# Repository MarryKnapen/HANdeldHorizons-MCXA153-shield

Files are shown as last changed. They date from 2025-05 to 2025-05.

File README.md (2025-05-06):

# FRDM-MCXA153 Arduino + MirkoBUS shield KICAD template

- Can be converted to Arduino Only or MikroBUS only template

# DO NOT USE THIS TEMPLATE, NO GUARANTEE IS GIVEN. THIS PRODUCT IS INCOMPLETE AND STILL REQUIRES PHYSICAL VERIFICATION OF COMPATIBILITY

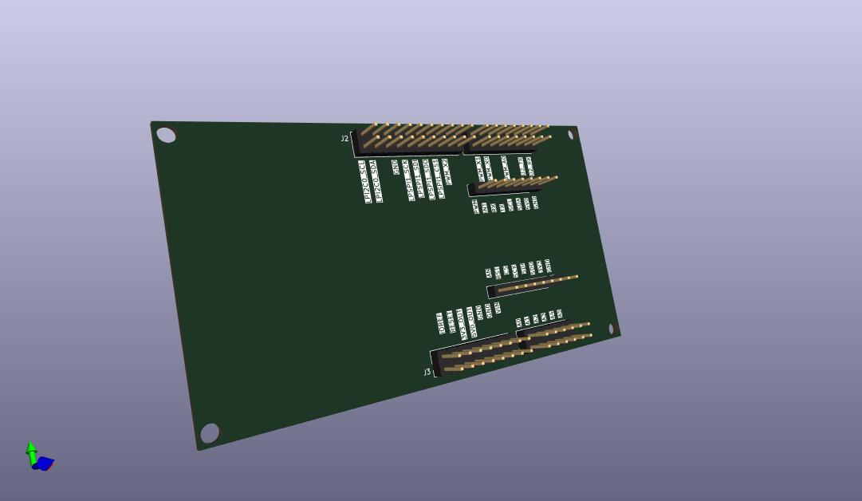
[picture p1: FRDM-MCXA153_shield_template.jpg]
template


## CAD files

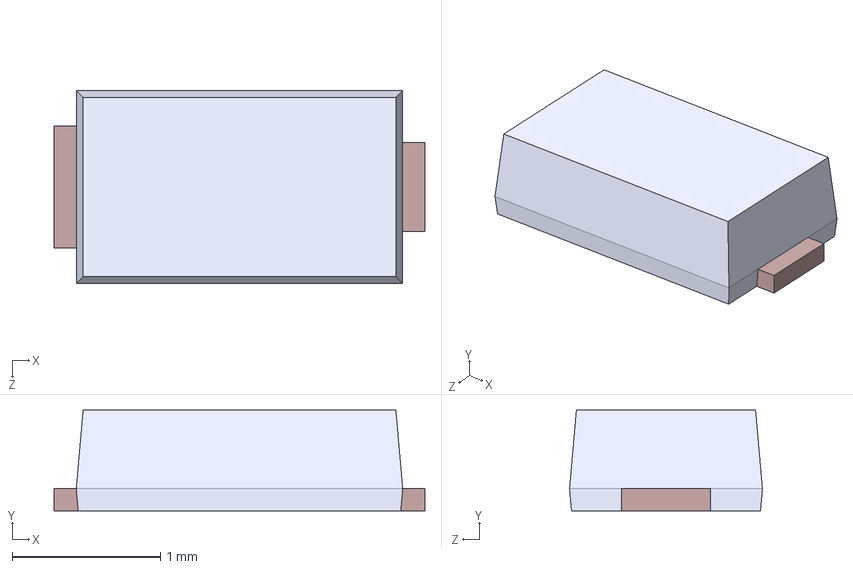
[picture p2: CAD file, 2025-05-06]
components/MSS1P3L_M3_89A/MSMP package.step
2.50 x 0.68 x 1.30 mm

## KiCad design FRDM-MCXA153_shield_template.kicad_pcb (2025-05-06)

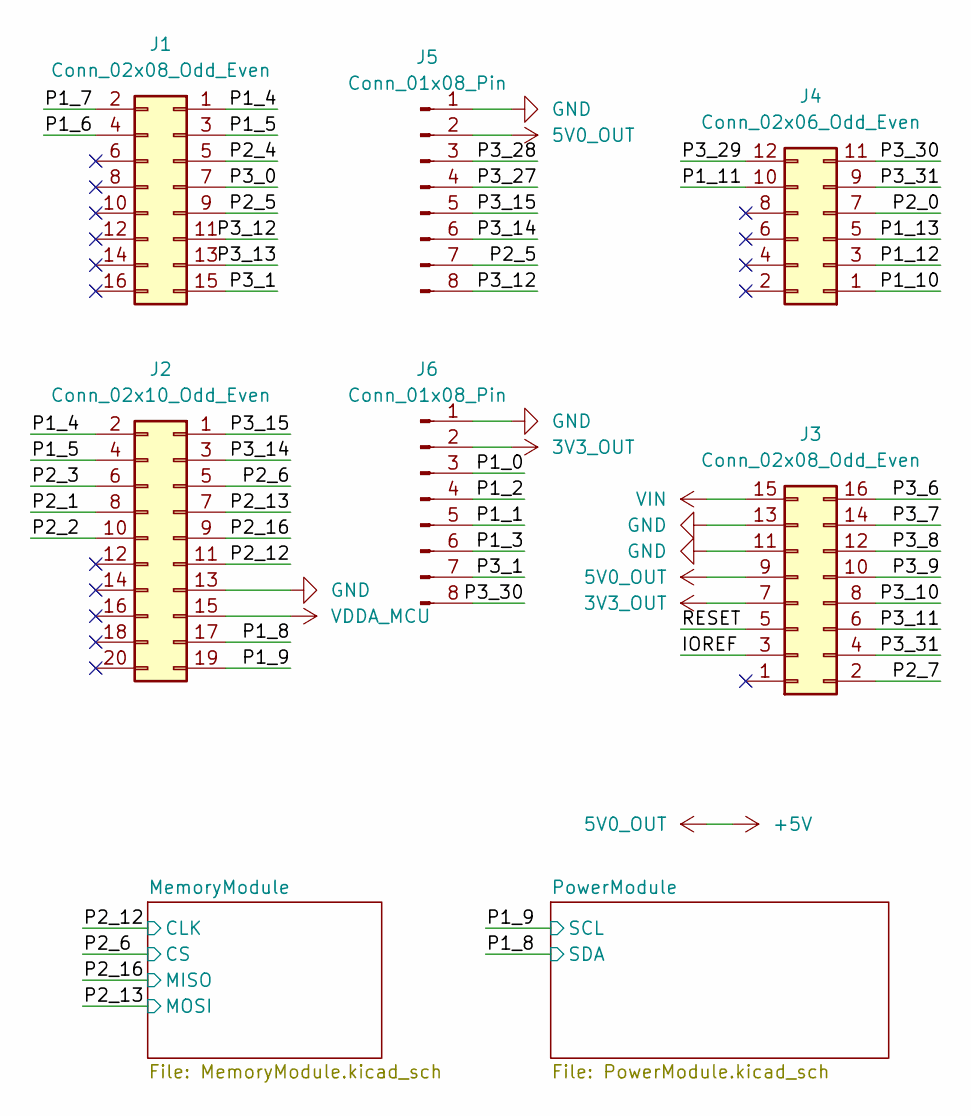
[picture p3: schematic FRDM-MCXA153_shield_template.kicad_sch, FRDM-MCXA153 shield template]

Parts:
J1, J3: Conn_02x08_Odd_Even; PinHeader_2x08_P2.54mm_Vertical
J2: Conn_02x10_Odd_Even; PinHeader_2x10_P2.54mm_Vertical
J4: Conn_02x06_Odd_Even; PinHeader_2x06_P2.54mm_Vertical
J5, J6: Conn_01x08_Pin; PinHeader_1x08_P2.54mm_Vertical

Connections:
3V3_OUT: J3.7, J6.2
+5V: J3.9, J5.2; also elsewhere on the board
/IOREF: J3.3
/P1_0: J6.3
/P1_1: J6.5
/P1_2: J6.4
/P1_3: J6.6
/P1_4: J1.1, J2.2
/P1_5: J1.3, J2.4
/P1_6: J1.4
/P1_7: J1.2
/P1_8: J2.17; also elsewhere on the board
/P1_9: J2.19; also elsewhere on the board
/P1_10: J4.1
/P1_11: J4.10
/P1_12: J4.3
/P1_13: J4.5
/P2_0: J4.7
/P2_1: J2.8
/P2_2: J2.10
/P2_3: J2.6
/P2_4: J1.5
/P2_5: J1.9, J5.7
/P2_6: J2.5; also elsewhere on the board
/P2_7: J3.2
/P2_12: J2.11; also elsewhere on the board
/P2_13: J2.7; also elsewhere on the board
/P2_16: J2.9; also elsewhere on the board
/P3_0: J1.7
/P3_1: J1.15, J6.7
/P3_6: J3.16
/P3_7: J3.14
/P3_8: J3.12
/P3_9: J3.10
/P3_10: J3.8
/P3_11: J3.6
/P3_12: J1.11, J5.8
/P3_13: J1.13
/P3_14: J2.3, J5.6
/P3_15: J2.1, J5.5
/P3_27: J5.4
/P3_28: J5.3
/P3_29: J4.12
/P3_30: J4.11, J6.8
/P3_31: J3.4, J4.9
/RESET: J3.5
GND: J2.13, J3.11, J3.13, J5.1, J6.1; also elsewhere on the board
VDDA_MCU: J2.15
VIN: J3.15

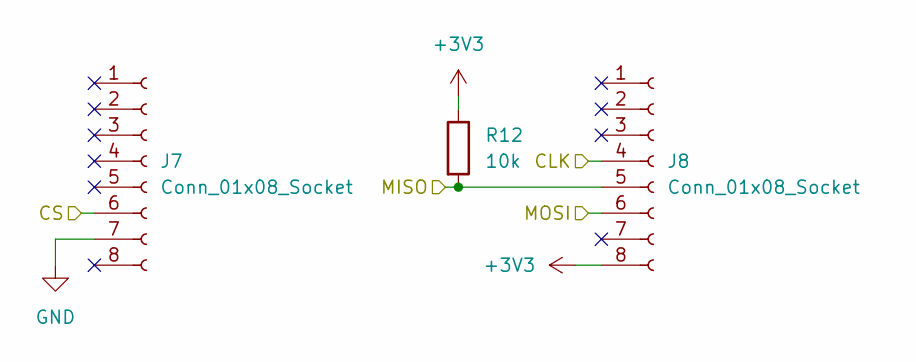
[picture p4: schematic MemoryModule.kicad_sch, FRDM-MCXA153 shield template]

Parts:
J7, J8: Conn_01x08_Socket; PinSocket_1x08_P2.54mm_Vertical
R12: 10k; R_1206_3216Metric_Pad1.30x1.75mm_HandSolder

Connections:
+3V3: J8.8, R12.1
/P2_6: J7.6; also elsewhere on the board
/P2_12: J8.4; also elsewhere on the board
/P2_13: J8.6; also elsewhere on the board
/P2_16: J8.5, R12.2; also elsewhere on the board
GND: J7.7; also elsewhere on the board

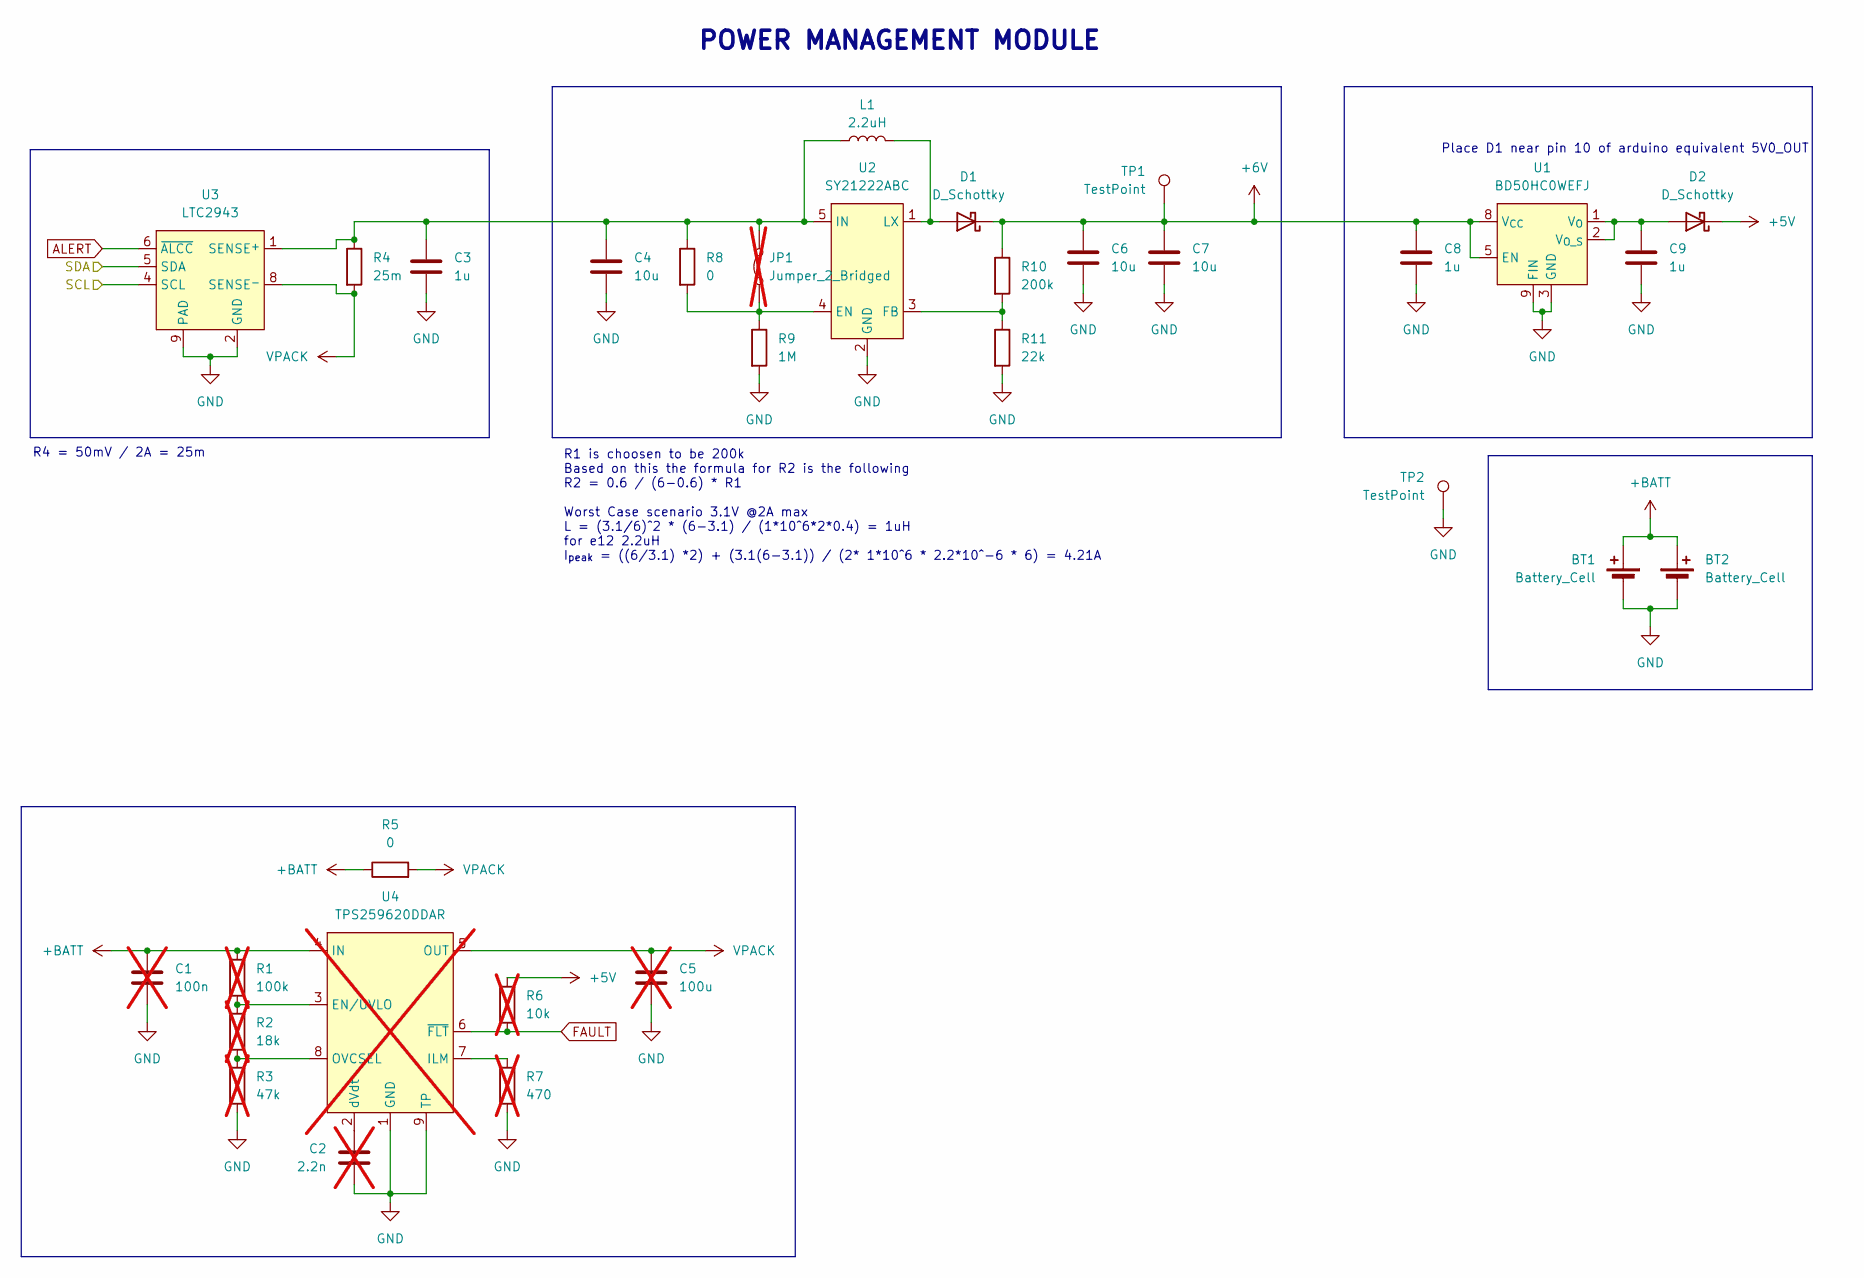
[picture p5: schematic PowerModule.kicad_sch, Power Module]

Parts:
BT1, BT2: Battery_Cell; SolderWire-0.75sqmm_1x02_P4.8mm_D1.25mm_OD2.3mm
C1: 100n; C_1206_3216Metric_Pad1.33x1.80mm_HandSolder; not fitted
C2: 2.2n; C_1206_3216Metric_Pad1.33x1.80mm_HandSolder; not fitted
C3, C8, C9: 1u; C_1206_3216Metric_Pad1.33x1.80mm_HandSolder
C4, C6, C7: 10u; C_1206_3216Metric_Pad1.33x1.80mm_HandSolder
C5: 100u; C_1206_3216Metric_Pad1.33x1.80mm_HandSolder; not fitted
D1: D_Schottky; D_PowerDI-123
D2: D_Schottky; D_MicroSMP_AK
JP1: Jumper_2_Bridged; PinHeader_1x02_P2.54mm_Vertical; not fitted
L1: 2.2uH; IND_LQH5BPN_MUR
R1: 100k; R_1206_3216Metric_Pad1.30x1.75mm_HandSolder; not fitted
R2: 18k; R_1206_3216Metric_Pad1.30x1.75mm_HandSolder; not fitted
R3: 47k; R_1206_3216Metric_Pad1.30x1.75mm_HandSolder; not fitted
R4: 25m; R_1206_3216Metric_Pad1.30x1.75mm_HandSolder
R5, R8: 0; R_1206_3216Metric_Pad1.30x1.75mm_HandSolder
R6: 10k; R_1206_3216Metric_Pad1.30x1.75mm_HandSolder; not fitted
R7: 470; R_1206_3216Metric_Pad1.30x1.75mm_HandSolder; not fitted
R9: 1M; R_1206_3216Metric_Pad1.30x1.75mm_HandSolder
R10: 200k; R_1206_3216Metric_Pad1.30x1.75mm_HandSolder
R11: 22k; R_1206_3216Metric_Pad1.30x1.75mm_HandSolder
TP1, TP2: TestPoint; PinHeader_1x01_P2.54mm_Vertical
U1: BD50HC0WEFJ; HTSOP-J8
U2: SY21222ABC; SOT-23-6
U3: LTC2943; DFN-8-1EP_3x3mm_P0.5mm_EP1.66x2.38mm
U4: TPS259620DDAR; SOIC-8-1EP_3.9x5.75mm_P1.27mm_EP2.4x3.1mm; not fitted

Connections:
+5V: D2.1 (K), R6.1; also elsewhere on the board
+6V: C6.1, C7.1, C8.1, D1.1 (K), R10.1, TP1.1, U1.5 (EN), U1.8 (V_{CC})
+BATT: BT1.1 (+), BT2.1 (+), C1.1, R1.1, R5.1, U4.4 (IN)
/P1_8: U3.5 (SDA); also elsewhere on the board
/P1_9: U3.4 (SCL); also elsewhere on the board
ALERT: U3.6 (~ALCC)
FAULT: R6.2, U4.6 (~FLT)
GND: BT1.2 (-), BT2.2 (-), C1.2, C2.2, C3.2, C4.2, C5.2, C6.2, C7.2, C8.2, C9.2, R3.2, R7.2, R9.2, R11.2, TP2.1, U1.3 (GND), U1.9 (FIN), U2.2 (GND), U3.2 (GND), U3.3 (GND), U3.7 (GND), U3.9 (PAD), U4.1 (GND), U4.9 (TP); also elsewhere on the board
unnamed: D1.2 (A), L1.2, U2.1 (LX)
unnamed: C9.1, D2.2 (A), U1.1 (V_{O}), U1.2 (V_{O_S})
unnamed: JP1.1 (A), R8.2, R9.1, U2.4 (EN)
unnamed: C3.1, C4.1, JP1.2 (B), L1.1, R4.1, R8.1, U2.5 (IN), U3.1 (SENSE^{+})
unnamed: R10.2, R11.1, U2.3 (FB)
unnamed: R1.2, R2.1, U4.3 (EN/UVLO)
unnamed: R7.1, U4.7 (ILM)
unnamed: R2.2, R3.1, U4.8 (OVCSEL)
unnamed: C2.1, U4.2 (dVdt)
VPACK: C5.1, R4.2, R5.2, U3.8 (SENSE^{-}), U4.5 (OUT)

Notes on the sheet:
R4 = 50mV / 2A = 25m
Place D1 near pin 10 of arduino equivalent 5V0_OUT
POWER MANAGEMENT MODULE
R1 is choosen to be 200k Based on this the formula for R2 is the following R2 = 0.6 / (6-0.6) * R1 Worst Case scenario 3.1V @2A max L = (3.1/6)^2 * (6-3.1) / (1*10^6*2*0.4) = 1uH for e12 2.2uH I_{peak} = ((6/3.1) *2) + (3.1(6-3.1)) / (2* 1*10^6 * 2.2*10^-6 * 6) = 4.21A

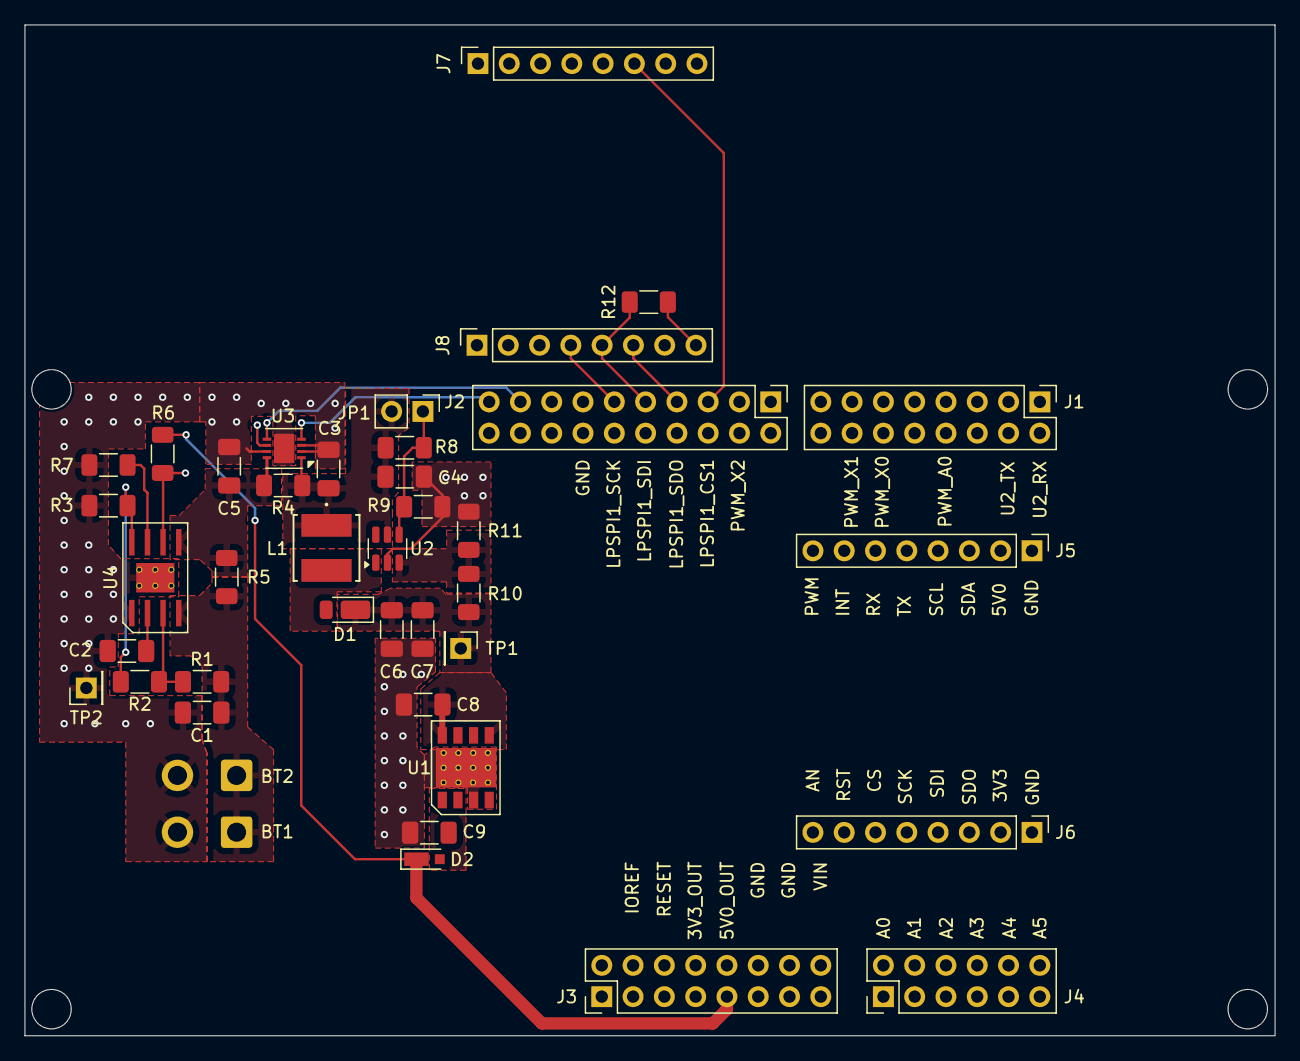
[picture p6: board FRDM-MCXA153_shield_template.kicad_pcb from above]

Board: 2 copper layers, 101.5 x 82.1 mm, 45 parts (0 on the bottom side), 32 nets.

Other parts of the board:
H1, H2, H3, H4: MountingHole; MountingHole_3.2mm_M3_ISO7380

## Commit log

2025-05-06 add power module
    [FRDM-MCXA153_shield_template.kicad_pcb, FRDM-MCXA153_shield_template.kicad_sch, MSMP package.step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]
2025-05-06 add memory module and increase size of shield
    [FRDM-MCXA153_shield_template.kicad_pcb, FRDM-MCXA153_shield_template.kicad_sch, MemoryModule.kicad_sch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]
